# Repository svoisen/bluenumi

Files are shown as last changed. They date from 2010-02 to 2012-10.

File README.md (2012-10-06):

Bluenumi Clock
==============

Bluenumi is a custom-designed 4-digit numitron clock featuring:

* Retro glowing numitron display featuring Russian IV-9 numitron tubes
* A DS1307 real time clock with backup battery for accurate timekeeping and alarm memory preservation during loss of power
* Blue LED underlighting for each digit, with pre-programmed fade patterns
* Laser cut acrylic case
* Programmable alarm
* 12- or 24-hour operating mode with AM/PM indicator light
* Easy display blanking for nighttime use and tube life preservation
* 100% open source hardware and software
* Arduino programming compatibility using standard TTL serial

For more information, or to order a clock kit or fully assembled, visit: [http://www.etsy.com/shop/VoisenDesign](http://www.etsy.com/shop/VoisenDesign).

Parts list (BOM), assembly instructions, and user's guide are [available on the wiki](https://github.com/svoisen/bluenumi/wiki).

Images
------



Firmware License
----------------

Copyright (C) 2009 - 2011 [Sean Voisen](http://sean.voisen.org)

Firmware code is released under the GNU GPL version 3:

This program is free software: you can redistribute it and/or modify it under the terms of the GNU General Public License as published by the Free Software Foundation, either version 3 of the License, or (at your option) any later version.

This program is distributed in the hope that it will be useful, but WITHOUT ANY WARRANTY; without even the implied warranty of MERCHANTABILITY or FITNESS FOR A PARTICULAR PURPOSE.  See the GNU General Public License for more details.

You should have received a copy of the GNU General Public License along with this program.  If not, see <http://www.gnu.org/licenses/>.

Schematics and Board Layout License
-----------------------------------

Copyright (C) 2009 - 2011 [Sean Voisen](http://sean.voisen.org)

Schematics and board layout are released under the [Creative Commons Attribution-ShareAlike 3.0 Unported](http://creativecommons.org/licenses/by-sa/3.0/) license.

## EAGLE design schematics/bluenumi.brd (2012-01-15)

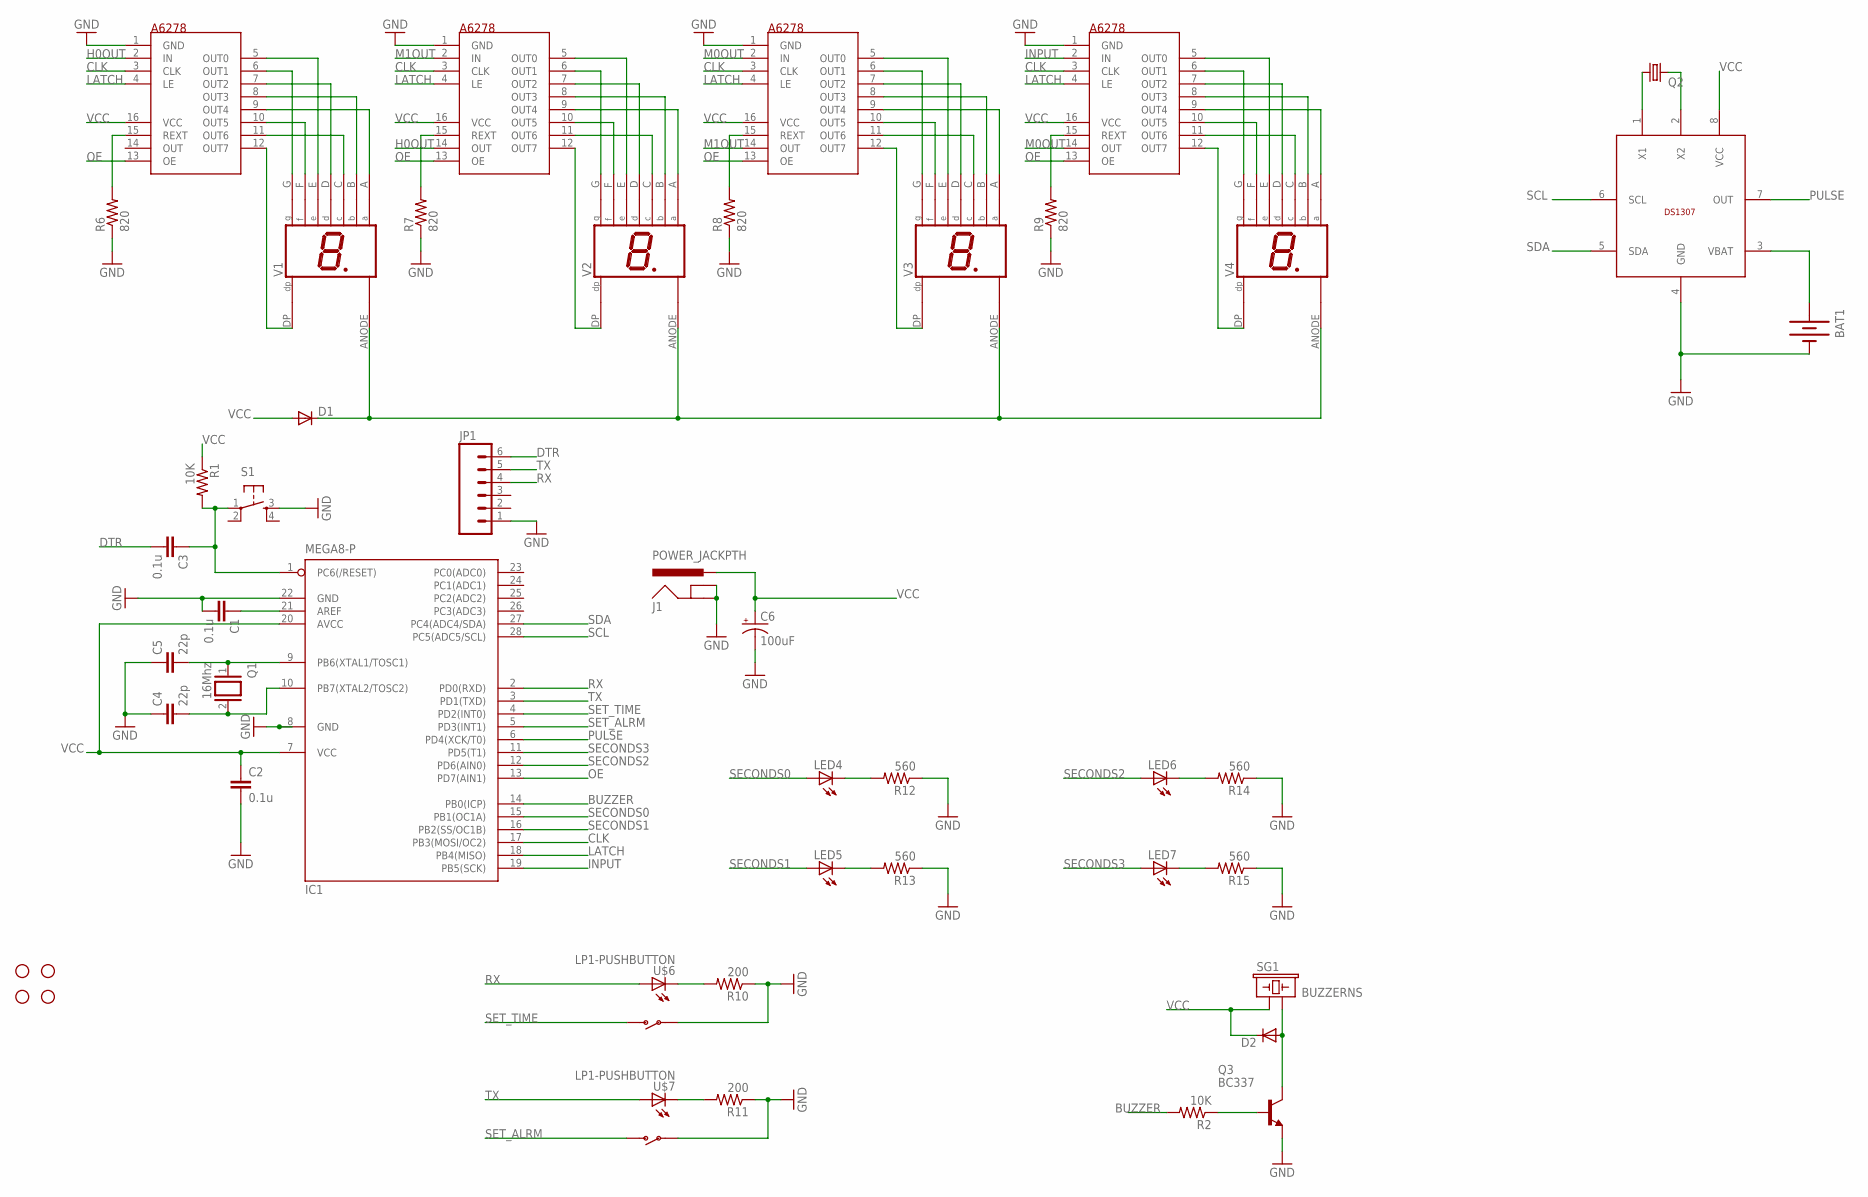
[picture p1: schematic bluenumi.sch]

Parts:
BAT1: BATTERY20PTH; BATTCOM_20MM_PTH
C1, C2, C3: 0.1u; CAP-PTH-SMALL
C4, C5: 22p; CAP-PTH-SMALL
C6: 100uF; CPOL-RADIAL-10UF-25V
D1, D2: DIODEPTH; DIODE-1N4001
IC1: MEGA8-P; DIL28-3
J1: POWER_JACKPTH; POWER_JACK_PTH
JP1: M06LOCK; 1X06_LOCK
LED4, LED5, LED6, LED7: LED5MM
Q1: 16Mhz; QS
Q2: CRYSTALTC26H; TC26H
Q3: BC337; TO92
R1, R2: 10K; AXIAL-0.3
R6, R7, R8, R9: 820; AXIAL-0.3
R10, R11: 200; AXIAL-0.3
R12, R13, R14, R15: 560; AXIAL-0.3
S1: TAC_SWITCHPTH; TACTILE-PTH
SG1: BUZZERNS; BUZZER-12MM-NS
U$1: TLC5916; DIL16
U$2, U$3, U$4: A6278EAT; DIL16
U$5: DS1307; DIL08
U$6, U$7: LP1-PUSHBUTTON
U$8, U$9, U$10, U$11: STAND-OFF
V1, V2, V3, V4: IV-9-UNDERLIT; 9PINTUBE-WIDE

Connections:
BUZZER: IC1.14 (PB0(ICP)), R2.P$2 (2)
CLK: IC1.17 (PB3(MOSI/OC2)), U$1.3 (CLK), U$2.3 (CLK), U$3.3 (CLK), U$4.3 (CLK)
DTR: C3.2, JP1.6
GND: BAT1.2 (-), C1.2, C2.2, C4.1, C5.1, C6.2 (-), IC1.8 (GND), IC1.22 (GND), J1.GND, J1.GNDBREAK, JP1.1, Q3.1 (E), R6.P$1 (1), R7.P$1 (1), R8.P$1 (1), R9.P$1 (1), R10.P$1 (1), R11.P$1 (1), R12.P$1 (1), R13.P$1 (1), R14.P$1 (1), R15.P$1 (1), S1.3, U$1.1 (GND), U$2.1 (GND), U$3.1 (GND), U$4.1 (GND), U$5.4 (GND), U$6.S2, U$7.S2
H0OUT: U$1.2 (IN), U$2.14 (OUT)
INPUT: IC1.19 (PB5(SCK)), U$4.2 (IN)
LATCH: IC1.18 (PB4(MISO)), U$1.4 (LE), U$2.4 (LE), U$3.4 (LE), U$4.4 (LE)
M0OUT: U$3.2 (IN), U$4.14 (OUT)
M1OUT: U$2.2 (IN), U$3.14 (OUT)
unnamed: U$1.5 (OUT0), V1.E
unnamed: U$1.6 (OUT1), V1.G
unnamed: U$1.7 (OUT2), V1.D
unnamed: U$1.8 (OUT3), V1.B
unnamed: U$1.9 (OUT4), V1.A
unnamed: U$1.10 (OUT5), V1.F
unnamed: U$1.11 (OUT6), V1.C
unnamed: U$1.12 (OUT7), V1.DP
unnamed: R11.P$2 (2), U$7.CATHODE
unnamed: U$2.12 (OUT7), V2.DP
unnamed: C5.2, IC1.9 (PB6(XTAL1/TOSC1)), Q1.1
unnamed: U$2.6 (OUT1), V2.G
unnamed: U$2.5 (OUT0), V2.E
unnamed: U$2.7 (OUT2), V2.D
unnamed: U$2.8 (OUT3), V2.B
unnamed: U$2.9 (OUT4), V2.A
unnamed: U$2.10 (OUT5), V2.F
unnamed: U$2.11 (OUT6), V2.C
unnamed: D1.C, V1.ANODE, V2.ANODE, V3.ANODE, V4.ANODE
unnamed: Q2.1, U$5.1 (X1)
unnamed: Q2.2, U$5.2 (X2)
unnamed: C4.2, IC1.10 (PB7(XTAL2/TOSC2)), Q1.2
unnamed: C3.1, IC1.1 (PC6(/RESET)), R1.P$2 (2), S1.1
unnamed: C1.1, IC1.21 (AREF)
unnamed: U$3.12 (OUT7), V3.DP
unnamed: U$3.11 (OUT6), V3.C
unnamed: U$3.10 (OUT5), V3.F
unnamed: U$3.9 (OUT4), V3.A
unnamed: U$3.8 (OUT3), V3.B
unnamed: U$3.7 (OUT2), V3.D
unnamed: U$3.6 (OUT1), V3.G
unnamed: U$3.5 (OUT0), V3.E
unnamed: R6.P$2 (2), U$1.15 (REXT)
unnamed: Q3.2 (B), R2.P$1 (1)
unnamed: D2.A, Q3.3 (C), SG1.- (2)
unnamed: R7.P$2 (2), U$2.15 (REXT)
unnamed: R8.P$2 (2), U$3.15 (REXT)
unnamed: R9.P$2 (2), U$4.15 (REXT)
unnamed: R10.P$2 (2), U$6.CATHODE
unnamed: U$4.11 (OUT6), V4.C
unnamed: U$4.10 (OUT5), V4.F
unnamed: U$4.9 (OUT4), V4.A
unnamed: U$4.8 (OUT3), V4.B
unnamed: U$4.7 (OUT2), V4.D
unnamed: U$4.6 (OUT1), V4.G
unnamed: U$4.5 (OUT0), V4.E
unnamed: LED4.K (C), R12.P$2 (2)
unnamed: U$4.12 (OUT7), V4.DP
unnamed: LED5.K (C), R13.P$2 (2)
unnamed: LED6.K (C), R14.P$2 (2)
unnamed: LED7.K (C), R15.P$2 (2)
unnamed: BAT1.1 (+), U$5.3 (VBAT)
OE: IC1.13 (PD7(AIN1)), U$1.13 (OE), U$2.13 (OE), U$3.13 (OE), U$4.13 (OE)
PULSE: IC1.6 (PD4(XCK/T0)), U$5.7 (OUT)
RX: IC1.2 (PD0(RXD)), JP1.4, U$6.ANODE
SCL: IC1.28 (PC5(ADC5/SCL)), U$5.6 (SCL)
SDA: IC1.27 (PC4(ADC4/SDA)), U$5.5 (SDA)
SECONDS0: IC1.15 (PB1(OC1A)), LED4.A
SECONDS1: IC1.16 (PB2(SS/OC1B)), LED5.A
SECONDS2: IC1.12 (PD6(AIN0)), LED6.A
SECONDS3: IC1.11 (PD5(T1)), LED7.A
SET_ALRM: IC1.5 (PD3(INT1)), U$7.S1
SET_TIME: IC1.4 (PD2(INT0)), U$6.S1
TX: IC1.3 (PD1(TXD)), JP1.5, U$7.ANODE
VCC: C2.1, C6.1 (+), D1.A, D2.C, IC1.7 (VCC), IC1.20 (AVCC), J1.PWR, R1.P$1 (1), SG1.+ (1), U$1.16 (VCC), U$2.16 (VCC), U$3.16 (VCC), U$4.16 (VCC), U$5.8 (VCC)

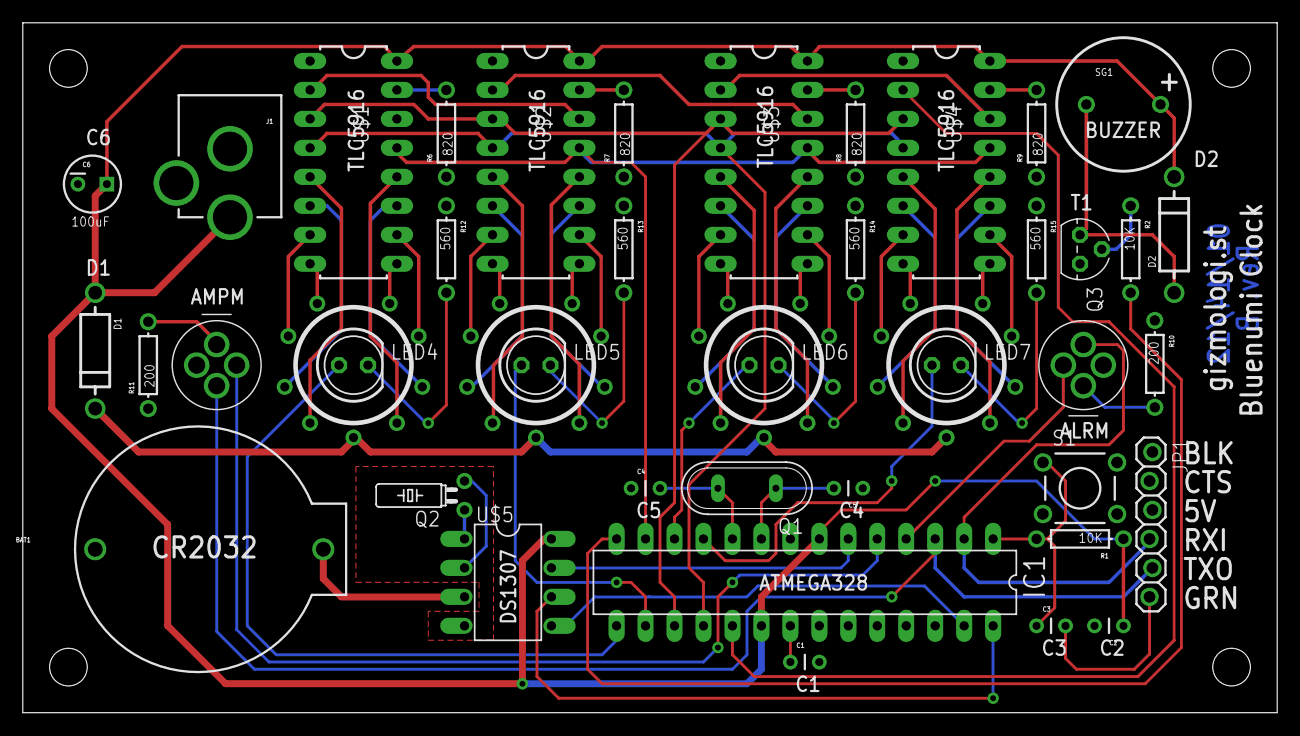
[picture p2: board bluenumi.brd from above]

Board: 2 copper layers, 110.0 x 60.5 mm, 48 parts (0 on the bottom side), 74 nets.

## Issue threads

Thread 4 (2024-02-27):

9PINTUBE-WIDE Part

BrookeDot, 2024-02-27:
Hi @svoisen,

I am wondering if you can upload the footprint/symbol for the ` 9PINTUBE-WIDE` part included in this board. I am making my own clock and having your footprint would jumpstart my PCB.

I looked and [your Eagle Library](https://github.com/svoisen/seanvoisen-eagle-libraries) was last updated prior to the release of this board.

Thanks!

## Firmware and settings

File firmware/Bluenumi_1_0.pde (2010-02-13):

/*******************************************************************************
 * Gizmologist Bluenumi Clock Firmware
 * Version 1.0
 *
 * Copyright (C) 2010 Gizmologist, LLC. All rights reserved.
 * Author: Sean Voisen
 * Last Modified: 12/31/2009
 *
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
 * You should have received a copy of the GNU Lesser General Public
 * License along with this library; if not, write to the Free Software
 * Foundation, Inc., 51 Franklin St, Fifth Floor, Boston, MA  02110-1301  USA
 ******************************************************************************/
 
#include <avr/interrupt.h> // Used for adding interrupts
#include "DS1307RTC.h" // Used for communicating with RTC

/*******************************************************************************
 * Pin Mappings
 /*****************************************************************************/
#define SECONDS0_PIN 9 // LED under 10s hour
#define SECONDS1_PIN 10 // LED under 1s hour
#define SECONDS2_PIN 11 // LED under 10s minute
#define SECONDS3_PIN 3 // LED under 1s minute
#define DATA_PIN 13 // Data input to A6278 shift registers
#define LATCH_PIN 12 // Latch control for A6278 shift registers
#define CLK_PIN 6 // Clock for A6278 shift registers
#define OE_PIN 7 // Output enable on A6278 shift registers, active low
#define AMPM_PIN 0 // Both RX and used for AMPM indicator LED
#define ALRM_PIN 1 // Both TX and used for alarm indicator LED
#define PIEZO_PIN 8 // Piezo alarm
#define HZ_PIN 4 // 1 Hz pulse from DS1307 RTC
#define LEFT_BTN_PIN 2 // Time set/left button
#define RIGHT_BTN_PIN 5 // Alarm set/right button

#define SDA_PIN 4 // Analog pin, used for 2wire communication to DS1307
#define SCL_PIN 5 // Analog pin, used for 2wire communicatino to DS1307

/*******************************************************************************
 * Mode Defines
 /*****************************************************************************/
#define RUN_MODE 0
#define RUN_BLANK_MODE 1
#define SET_TIME_MODE 2
#define SET_ALARM_MODE 3

/*******************************************************************************
 * Misc Defines
 /*****************************************************************************/
#define DEBOUNCE_INTERVAL 20 // Interval to wait when debouncing buttons
#define LONG_PRESS 3000 // Length of time that qualifies as a long button press
#define BLINK_DELAY 500 // Length of display blink on/off interval

/*******************************************************************************
 * Time/Alarm Variables
 /*****************************************************************************/
unsigned int alarmHours, alarmMinutes = 0; // Variables that store when to set off the alarm!

/*******************************************************************************
 * Misc Variables
 /*****************************************************************************/
const int numbers[] = {123, 96, 87, 118, 108, 62, 47, 112, 127, 124};  // Array translates BCD to 7-segment output
volatile boolean updateDisplay = true; // Set to true when time display needs updating
byte mode = RUN_MODE; // Default to run mode
volatile unsigned long timeSetButtonPressTime = 0; // Keeps track of when time (left) button was pressed
volatile unsigned long alarmSetButtonPressTime = 0; // Keeps track of when alarm (right) button was pressed

/**
 * Sets up the program before running the continuous loop()
 */
void setup()
{
  // Set up pin modes
  pinMode( SECONDS0_PIN, OUTPUT );
  pinMode( SECONDS1_PIN, OUTPUT );
  pinMode( SECONDS2_PIN, OUTPUT );
  pinMode( SECONDS3_PIN, OUTPUT );
  pinMode( DATA_PIN, OUTPUT );
  pinMode( LATCH_PIN, OUTPUT );
  pinMode( CLK_PIN, OUTPUT );
  pinMode( OE_PIN, OUTPUT );
  pinMode( AMPM_PIN, OUTPUT );
  pinMode( ALRM_PIN, OUTPUT );
  pinMode( PIEZO_PIN, OUTPUT );
  pinMode( HZ_PIN, INPUT );
  pinMode( LEFT_BTN_PIN, INPUT );
  pinMode( RIGHT_BTN_PIN, INPUT );
  
  // Pull-up resistors for buttons and DS1307 square wave
  digitalWrite( HZ_PIN, HIGH );
  digitalWrite( LEFT_BTN_PIN, HIGH );
  digitalWrite( RIGHT_BTN_PIN, HIGH );
  
  // Enable output
  digitalWrite( OE_PIN, LOW );
  
  // Set up interrupts
  attachInterrupt( 0, leftButtonPressed, LOW );
  attachInterrupt( 1, rightButtonPressed, LOW );
  
  // Arduino environment has only 2 interrupts, here we add a 3rd interrupt on Arduino digital pin 4 (PCINT20 XCK/TO)
  // This interrupt will be used to interface with the DS1307RTC square wave, and will be called every second (1Hz)
  PCICR |= (1 << PCIE2);
  PCMSK2 |= (1 << PCINT20);
  interrupts();
  
  // Start 2-wire communication with DS1307
  DS1307RTC.begin();
  
  // Check CH bit in DS1307, if it's 1 then the clock is not started
  //if( !DS1307RTC.isRunning() ) {
    // Clock is not running, probably powering up for the first time, change mode to set time
    //mode = SET_TIME_MODE;
    DS1307RTC.setDateTime( 0, 0, 12, 1, 1, 1, 10, true, true, true, 0x10);
  //}
  
  Serial.begin(9600);
}

/**
 * This function runs continously as long as the clock is powered on. When the clock is not
 * powered on the DS1307 will continue to keep time as long as it has a battery :)
 */
void loop()
{
  // Take care of any button presses first
  if( setTimeButtonPressTime > 0 ) {
    handleTimeButtonPress();
  }
  
  if( setAlarmButtonPress > 0 ) {
    handleAlarmButtonPress();
  }
  
  switch( mode ) {
    case RUN_MODE:
      if( updateDisplay ) { // Only update time display as necessary
        fetchAndOutputTime();
        updateDisplay = false;
      }
      break;
    
    case RUN_BLANK_MODE:
      break;
      
    case SET_TIME_MODE:
      if( updateBlink() ) { // Returns true when time display should be shown
      }
      else {
        blankDisplay();
      }
      break;
      
    case SET_ALARM_MODE:
      break;
  }
}

/**
 * Used for blinking the display on and off. Determines if the display should be on (true) or off (false) using
 * a set interval BLINK_DELAY.
 */
boolean updateBlink()
{
  static unsigned long lastBlinkTime = 0;
  static boolean blinkOn = true;
  if( millis() - lastBlinkTime >= BLINK_DELAY ) {
    blinkOn = !blinkOn;
    lastBlinkTime = millis();
  }
  return blinkOn;
}

/**
 * Fetches the time from the DS1307 RTC and displays the time on the numitrons.
 */
void fetchAndOutputTime()
{
  byte second, minute, hour, dayOfWeek, dayOfMonth, month, year;
  bool twelveHourMode, ampm;
  DS1307RTC.getDateTime( &second, &minute, &hour, &dayOfWeek, &dayOfMonth, &month, &year, &twelveHourMode, &ampm );
  
  digitalWrite( LATCH_PIN, LOW );
  shiftOut( DATA_PIN, CLK_PIN, MSBFIRST, numbers[hour/10] );
  shiftOut( DATA_PIN, CLK_PIN, MSBFIRST, numbers[hour%10] );
  shiftOut( DATA_PIN, CLK_PIN, MSBFIRST, numbers[minute/10] );
  shiftOut( DATA_PIN, CLK_PIN, MSBFIRST, numbers[minute%10] );
  digitalWrite( LATCH_PIN, HIGH );
  
  digitalWrite( AMPM_PIN, (ampm ? HIGH : LOW) ); // Also output AMPM indicator light
}

void leftButtonPressed()
{
  static unsigned long lastInterruptTime = 0;
  unsigned long interruptTime = millis();
  
  if( interruptTime - lastInterruptTime > DEBOUNCE_INTERVAL ) {
    timeSetButtonPressTime = interruptTime;
  }
  
  lastInterruptTime = interruptTime;
}

void rightButtonPressed()
{
  static unsigned long lastInterruptTime = 0;
  unsigned long interruptTime = millis();
  
  if( interruptTime - lastInterruptTime > DEBOUNCE_INTERVAL ) {
    alarmSetButtonPressTime = interruptTime;
  }
  
  lastInterruptTime = interruptTime;
}

void setTimeReleased()
{
}

void setAlarmReleased()
{
}

void handleTimeButtonPress()
{
  boolean longPress = false;
  
  while( digitalRead( LEFT_BTN_PIN ) == LOW ) {
    if( millis() - timeButtonPressTime >= LONG_PRESS ) {
      longPress = true;
    }
  }
  
  switch( mode ) {
    case RUN_MODE:
      if( longPress ) {
        mode = SET_TIME_MODE;
      }
      break;
      
    case SET_TIME_MODE:
      if( longPress ) {
        // Save new time in DS1307
        mode = RUN_MODE;
      }
      else {
      }
      break;
  }
  
  timeButtonPressTime = 0;
}

void handleAlarmButtonPress()
{
  boolean longPress = false;
  
  while( digitalRead( RIGHT_BTN_PIN ) == LOW ) {
    if( millis() - alarmButtonPressTime >= LONG_PRESS ) {
      longPress = true;
    }
  }
  
  switch( mode ) {
    case RUN_MODE:
      if( longPress ) {
        mode = SET_ALARM_MODE;
      }
      break;
  }
}

/**
 * Blanks the display, both numitrons and all LEDs.
 */
void blankDisplay()
{
  digitalWrite( OE_PIN, HIGH );
  digitalWrite( SECONDS0_PIN, LOW );
  digitalWrite( SECONDS1_PIN, LOW );
  digitalWrite( SECONDS2_PIN, LOW );
  digitalWrite( SECONDS3_PIN, LOW );
  digitalWrite( AMPM_PIN, LOW );
  digitalWrite( ALRM_PIN, LOW );
}

/**
 * This interrupt will be called every time the DS1307 square wave pin changes. At 1Hz this means
 * 2 changes per second (high to low, low to high).
 */
ISR( PCINT2_vect )
{
  // Instead of digitalRead, we'll read the port directly for Arduino digital pin 4 (which resides in PORTD)
  // This keeps the execution time of the interrupt a bit shorter
  // Here, we look for when pin 4 (4th bit in PIND) is pulled low (value == 0), meaning 1 second has passed
  if( (PIND & 0x10) == 0 ) {
    // TICK! Update the time!
    updateDisplay = true;
  }
}

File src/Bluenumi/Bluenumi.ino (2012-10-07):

/*******************************************************************************
 * Copyright (C) 2011 Sean Voisen <http://sean.voisen.org>
 *
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
 * You should have received a copy of the GNU General Public License
 * along with this program.  If not, see <http://www.gnu.org/licenses/>.
 ******************************************************************************/

#include <avr/interrupt.h> // Used for adding interrupts
#include "Wire.h" // Used for communicating over I2C
#include "DS1307RTC.h" // Library for RTC tasks
#include "Bluenumi.h" // Locally-used data types
#include "Display.h" // Numitron display control
#include "LEDController.h" // Underlighting control
#include "AudioController.h" // Piezo buzzer control
#include "Bounce.h" // Button debouncing

/*******************************************************************************
 *
 * Pin Mappings
 *
 ******************************************************************************/
#define AMPM_PIN 1 // Both TX and used for AMPM indicator LED
#define ALRM_PIN 0 // Both RX and used for alarm indicator LED
#define HZ_PIN 4 // 1 Hz pulse from DS1307 RTC
#define TIME_BTN_PIN 3 // Time set/left button
#define ALRM_BTN_PIN 2 // Alarm set/right button

/*******************************************************************************
 *
 * Misc Defines
 *
 ******************************************************************************/
#define DEBOUNCE_INTERVAL 20 // Interval to wait when debouncing buttons
#define LONG_PRESS 2000 // Length of time that qualifies as a long button press
#define BLINK_DELAY 500 // Length of display blink on/off interval

#define UNBLANK_INTERVAL 3000 // Length of time to temp unblank display in 
                              // run blank mode
#define ALARM_SHOW_INTERVAL 2000 // Length of time to flash alarm time when
                                 // enabling the alarm

/*******************************************************************************
 *
 * Debug Defines
 *
 ******************************************************************************/
//#define DEBUG true
//#define DEBUG_BAUD 9600

/*******************************************************************************
 *
 * Variables
 *
 ******************************************************************************/
byte timeSetHours = 12;
byte timeSetMinutes = 0;
boolean timeSetTwelveHourMode = true;
boolean timeSetAmPm = false;

byte alarmHours = 12; 
byte alarmMinutes = 0;
boolean alarmAmPm = false;
boolean alarmEnabled = false;
boolean alarmRecentlySnuffed = false;

boolean skipNextBlink = false;

Bounce timeSetButtonDebouncer = Bounce(TIME_BTN_PIN, DEBOUNCE_INTERVAL);
Bounce alarmSetButtonDebouncer = Bounce(ALRM_BTN_PIN, DEBOUNCE_INTERVAL);

// Timer to track temporary display unblanking when in run blank mode
unsigned long unblankTime = 0;

// Set to true when time display needs updating
volatile boolean displayDirty = true; 

// Keeps track of current run mode (RUN, SET_TIME, etc.)
enum RunMode currentRunMode = RUN;

// Keeps track of current sub-mode when setting time and alarm
enum SetMode currentSetMode = NONE;

// Keeps track of when time (left) button was pressed, mostly used to detect
// long presses (this value is set during an interrupt)
volatile unsigned long timeSetButtonPressTime = 0;

// Keeps track of when alarm (right) button was pressed, mostly used to detect
// long presses (this value is set during an interrupt)
volatile unsigned long alarmSetButtonPressTime = 0; 

// Function pointers for state machine handler functions
ModeHandler runModeHandlerMap[NUM_RUN_MODES] = {NULL};
ModeHandler setModeHandlerMap[NUM_SET_MODES] = {NULL};
ButtonHandler timeButtonHandlerMap[NUM_RUN_MODES] = {NULL};
ButtonHandler alarmButtonHandlerMap[NUM_RUN_MODES] = {NULL};
CycleHandler setModeCycleHandlerMap[NUM_SET_MODES] = {NULL};

/*******************************************************************************
 *
 * Arduino "Setup" and "Loop"
 *
 ******************************************************************************/

void setup()
{
#if DEBUG
Serial.begin(DEBUG_BAUD);
Serial.println("Bluenumi");
Serial.println("Firmware Version 001");
#endif
 
  // Set up pin modes
  pinMode(AMPM_PIN, OUTPUT);
  pinMode(ALRM_PIN, OUTPUT);
  pinMode(HZ_PIN, INPUT);
  pinMode(TIME_BTN_PIN, INPUT);
  pinMode(ALRM_BTN_PIN, INPUT);
 
  // Pull-up resistors for buttons and DS1307 square wave
  digitalWrite(HZ_PIN, HIGH);
  digitalWrite(TIME_BTN_PIN, HIGH);
  digitalWrite(ALRM_BTN_PIN, HIGH);
  
  // The Arduino libraries do not support enough interrupts, so here we use
  // standard AVR libc interrupt vectors for the two buttons, and the RTC
  // square wave
  PCICR |= (1 << PCIE2);
  PCMSK2 |= (1 << PCINT18); // Alarm button
  PCMSK2 |= (1 << PCINT20); // RTC square wave
  PCMSK2 |= (1 << PCINT19); // Time button

  // Start 2-wire communication with DS1307
  DS1307RTC.begin();

  // Start numitron display
  Display.begin();

  // Start LED patterns
  LEDs.begin();

  // Map handlers
  mapModeHandlers();
  mapButtonHandlers();
  mapCycleHandlers();

  // Set alarm indicator
  updateAlarmIndicator();
  
  // Check CH bit in DS1307, if it's 1 then the clock is not started
  if (!DS1307RTC.isRunning()) 
  {
#if DEBUG
Serial.println("RTC not running; switching to set time mode");
#endif
    // Start at default time
    DS1307RTC.setDateTime(0, timeSetMinutes, timeSetHours, 1, 1, 1, 0, 
        timeSetTwelveHourMode, timeSetAmPm, true, 0x10);

    // Set default alarm settings
    saveAlarmToRam();

    // Clock is not running, probably powering up for the first time, change 
    // mode to set time
    changeRunMode(SET_TIME);
  }
  else
  {
    getAlarmFromRam();
#if DEBUG
Serial.println("Got alarm settings from RAM");
Serial.print(alarmHours);
Serial.print(":");
Serial.println(alarmMinutes);
#endif
  }
}

void loop()
{
  // Take care of any button presses first
  if (timeSetButtonPressTime > 0 && alarmSetButtonPressTime > 0)
  {
    processDualButtonPress();
  }
  else if (timeSetButtonPressTime > 0)
  {
    processTimeButtonPress();
  }
  else if (alarmSetButtonPressTime > 0)
  {
    processAlarmButtonPress();
  }
  
  // Call the handler function for the current mode (state)
  runModeHandlerMap[currentRunMode]();
}

/*******************************************************************************
 *
 * Additional Setup
 *
 ******************************************************************************/
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

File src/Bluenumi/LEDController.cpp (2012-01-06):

/*******************************************************************************
 * Copyright (C) 2011 Sean Voisen <http://sean.voisen.org>
 *
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
 * You should have received a copy of the GNU General Public License
 * along with this program.  If not, see <http://www.gnu.org/licenses/>.
 ******************************************************************************/

#include "LEDController.h"

LEDController::LEDController()
{
  mapHandlers();
}

void LEDController::begin()
{
  enabled = true;
  paused = false;
  currentType = ROLLING_BREATHE;
  
  pinMode(SECONDS0_PIN, OUTPUT);
  pinMode(SECONDS1_PIN, OUTPUT);
  pinMode(SECONDS2_PIN, OUTPUT);
  pinMode(SECONDS3_PIN, OUTPUT);
}

void LEDController::update()
{
  if (!enabled || paused)
    return;

  CALL_MEMBER_FN(this, patternHandlerMap[currentType])();
}

void LEDController::pause()
{
  paused = true;
}

void LEDController::resume()
{
  paused = false;
}

void LEDController::setEnabled(bool value)
{
  enabled = value;
  setLEDStates(value, value, value, value);
}

void LEDController::setLEDStates(bool led0, bool led1, bool led2, bool led3)
{
  digitalWrite(SECONDS0_PIN, led0);
  digitalWrite(SECONDS1_PIN, led1);
  digitalWrite(SECONDS2_PIN, led2);
  digitalWrite(SECONDS3_PIN, led3);
}

void LEDController::mapHandlers()
{
  patternHandlerMap[BREATHE] = &LEDController::breatheHandler;
  patternHandlerMap[ROLLING_BREATHE] = &LEDController::rollingBreatheHandler;
}

void LEDController::breatheHandler()
{
  float val = calculateBreatheVal(PI/2.0, 0.0, 4000);
  analogWrite(SECONDS0_PIN, val);
  analogWrite(SECONDS1_PIN, val);
  analogWrite(SECONDS2_PIN, val);
  analogWrite(SECONDS3_PIN, val);
}

void LEDController::rollingBreatheHandler()
{
  float freqAdj = PI/2.0;
  analogWrite(SECONDS3_PIN, calculateBreatheVal(freqAdj, 0.0, 4000));
  analogWrite(SECONDS2_PIN, calculateBreatheVal(freqAdj, PI/4.0, 4000));
  analogWrite(SECONDS1_PIN, calculateBreatheVal(freqAdj, PI/2.0, 4000)); 
  analogWrite(SECONDS0_PIN, calculateBreatheVal(freqAdj, 3*PI/4.0, 4000));
}

float LEDController::calculateBreatheVal(float frequencyAdjust, float offset, int periodicity)
{
  float val = (millis() % periodicity) / 1000.0;
  return (exp(sin(val * frequencyAdjust + offset)) - 0.36787944)*108.0;
}

LEDController LEDs = LEDController();

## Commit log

2010-02-13 Add Eagle files
    [bluenumi.brd, bluenumi.sch]
2011-10-30 Use built-in Arduino I2C library Temp disable interrupts for buttons
2011-10-30 Rename folders Add README
    [bluenumi.brd, bluenumi.sch]
2011-11-02 Fix interrupt issues Begin display blinking for time set mode
    [Bluenumi.pde]
2011-11-02 Use function pointers for mode map instead of giant switch statement
2011-11-08 Fix bug with setting minute ones
    [Bluenumi.pde]
2011-11-08 Finish time setting mechanism Improve long button presses
2011-11-10 Begin work on LED pattern generation
2011-11-11 Rename Pattern to LEDController Adding rolling breathe pattern
2011-11-28 Update README with new license for schematics
2011-12-09 Temp set beep to 2048 Fix problem with initial alarm hours setting
    [Bluenumi.pde]
2011-12-12 Save alarm to RAM Fetch alarm from RAM on restart from mains power Fix bug with buffer overflow in number of run modes
    [Bluenumi.pde, DS1307RTC.cpp]
2011-12-12 Fix bugs with alarm retention on powerup
    [Bluenumi.pde]
2011-12-12 Fix bug with alarm not turning on in run blank mode
    [Bluenumi.pde, Display.cpp, Display.h]
2011-12-14 Fix skipNextBlink bug when flashing is off Add melody when switching to set time mode
    [Bluenumi.pde]
2011-12-15 Fix bug where switch from 24- to 12-hour mode could leave hours at 00
    [Bluenumi.pde]
2011-12-23 Add gitignore Update schematic to include reverse EMF protection diode Drive buzzer via transistor Remove 1K resistors on TX/RX Remove extra power diode and jumpers
    [bluenumi.brd, bluenumi.sch]
2011-12-23 Clean up board layout
    [bluenumi.brd]
2012-01-06 Fix bug where large values of millis() cause stuttering in LED fade pattern
    [LEDController.cpp, LEDController.h]
2012-01-15 Create gerber files Update board and schematic so that LED PWM is not on Arduino pins 3 or 11
    [bluenumi.brd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]
2012-01-15 Remove unused gerber files
    [bluenumi.GTP]
2012-08-12 Update pin mappings to match board revision B layout
2012-09-08 Update gitignore Fix mis-mapped buttons
    [Bluenumi.ino]
2012-09-12 Retab Bounce.cpp Fix debounce interval and interrupt used for time set pin
    [Bluenumi.ino]
